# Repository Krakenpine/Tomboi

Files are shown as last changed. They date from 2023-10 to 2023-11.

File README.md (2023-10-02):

# Tomboi
 Sample player with Daisy

 Very overengineered with effects and tonally playable multisampled sounds.
 Currently this repository includes only seven drum samples from free libraries, using raw multisamples from rompler-synth woud probably be a copyright violation, so I need to create my own for public examples.

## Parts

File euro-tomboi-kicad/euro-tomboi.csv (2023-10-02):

Source: | E:\Daisy\Tomboi\euro-tomboi-kicad\euro-tomboi.kicad_sch
Date: | 02/10/2023 11:10:50
Tool: | Eeschema (6.0.0)
Generator: | C:\Program Files\KiCad\6.0\bin\scripting\plugins/bom_csv_grouped_by_value.py
Component Count: | 72
Individual Components:
Item | Qty | Reference(s) | Value | LibPart | Footprint | Datasheet
 |  | C1 | 10n | Device:C | Capacitor_THT:C_Disc_D5.0mm_W2.5mm_P5.00mm | ~
 |  | C2 | 10n | Device:C | Capacitor_THT:C_Disc_D5.0mm_W2.5mm_P5.00mm | ~
 |  | C3 | 10n | Device:C | Capacitor_THT:C_Disc_D5.0mm_W2.5mm_P5.00mm | ~
 |  | C4 | 100n | Device:C | Capacitor_THT:C_Disc_D5.0mm_W2.5mm_P5.00mm | ~
 |  | C5 | 100n | Device:C | Capacitor_THT:C_Disc_D5.0mm_W2.5mm_P5.00mm | ~
 |  | C6 | 100n | Device:C | Capacitor_THT:C_Disc_D5.0mm_W2.5mm_P5.00mm | ~
 |  | C7 | 10u | Device:C_Polarized | Capacitor_THT:CP_Radial_D5.0mm_P2.50mm | ~
 |  | C8 | 10u | Device:C_Polarized | Capacitor_THT:CP_Radial_D5.0mm_P2.50mm | ~
 |  | C9 | 100n | Device:C | Capacitor_THT:C_Disc_D5.0mm_W2.5mm_P5.00mm | ~
 |  | C10 | 100n | Device:C | Capacitor_THT:C_Disc_D5.0mm_W2.5mm_P5.00mm | ~
 |  | D1 | BAT42 | Diode:BAT42 | Diode_THT:D_DO-35_SOD27_P7.62mm_Horizontal | http://www.vishay.com/docs/85660/bat42.pdf
 |  | D2 | BAT42 | Diode:BAT42 | Diode_THT:D_DO-35_SOD27_P7.62mm_Horizontal | http://www.vishay.com/docs/85660/bat42.pdf
 |  | D3 | BAT42 | Diode:BAT42 | Diode_THT:D_DO-35_SOD27_P7.62mm_Horizontal | http://www.vishay.com/docs/85660/bat42.pdf
 |  | D4 | BAT42 | Diode:BAT42 | Diode_THT:D_DO-35_SOD27_P7.62mm_Horizontal | http://www.vishay.com/docs/85660/bat42.pdf
 |  | D5 | BAT42 | Diode:BAT42 | Diode_THT:D_DO-35_SOD27_P7.62mm_Horizontal | http://www.vishay.com/docs/85660/bat42.pdf
 |  | D6 | BAT42 | Diode:BAT42 | Diode_THT:D_DO-35_SOD27_P7.62mm_Horizontal | http://www.vishay.com/docs/85660/bat42.pdf
 |  | D7 | BAT42 | Diode:BAT42 | Diode_THT:D_DO-35_SOD27_P7.62mm_Horizontal | http://www.vishay.com/docs/85660/bat42.pdf
 |  | D8 | BAT42 | Diode:BAT42 | Diode_THT:D_DO-35_SOD27_P7.62mm_Horizontal | http://www.vishay.com/docs/85660/bat42.pdf
 |  | J1 | Output | Connector:AudioJack2_SwitchT | omat:Jack_3.5mm_QingPu_WQP-PJ398SM_Vertical_CircularHoles_mid | ~
 |  | J2 | Trig_1 | Connector:AudioJack2_SwitchT | omat:Jack_3.5mm_QingPu_WQP-PJ398SM_Vertical_CircularHoles_mid | ~
 |  | J3 | Trig_2 | Connector:AudioJack2_SwitchT | omat:Jack_3.5mm_QingPu_WQP-PJ398SM_Vertical_CircularHoles_mid | ~
 |  | J4 | Trig_3 | Connector:AudioJack2_SwitchT | omat:Jack_3.5mm_QingPu_WQP-PJ398SM_Vertical_CircularHoles_mid | ~
 |  | J5 | CV_1 | Connector:AudioJack2_SwitchT | omat:Jack_3.5mm_QingPu_WQP-PJ398SM_Vertical_CircularHoles_mid | ~
 |  | J6 | CV_2 | Connector:AudioJack2_SwitchT | omat:Jack_3.5mm_QingPu_WQP-PJ398SM_Vertical_CircularHoles_mid | ~
 |  | J7 | CV_3 | Connector:AudioJack2_SwitchT | omat:Jack_3.5mm_QingPu_WQP-PJ398SM_Vertical_CircularHoles_mid | ~
 |  | J8 | Conn_01x16_Female | Connector:Conn_01x16_Female | Connector_PinSocket_2.54mm:PinSocket_1x16_P2.54mm_Vertical | ~
 |  | J9 | Conn_01x16_Male | Connector:Conn_01x16_Male | Connector_PinHeader_2.54mm:PinHeader_1x16_P2.54mm_Vertical | ~
 |  | J10 | Conn_02x05_Odd_Even | Connector_Generic:Conn_02x05_Odd_Even | Connector_PinHeader_2.54mm:PinHeader_2x05_P2.54mm_Vertical | ~
 |  | R1 | 66.5k | Device:R | omat:Omaresistor2 | ~
 |  | R2 | 200k | Device:R | omat:Omaresistor2 | ~
 |  | R3 | 66.5k | Device:R | omat:Omaresistor2 | ~
 |  | R4 | 200k | Device:R | omat:Omaresistor2 | ~
 |  | R5 | 66.5k | Device:R | omat:Omaresistor2 | ~
 |  | R6 | 200k | Device:R | omat:Omaresistor2 | ~
 |  | R7 | 1k | Device:R | omat:Omaresistor2 | ~
 |  | R8 | 1k | Device:R | omat:Omaresistor2 | ~
 |  | R9 | 1k | Device:R | omat:Omaresistor2 | ~
 |  | R10 | 200k | Device:R | omat:Omaresistor2 | ~
 |  | R11 | 200k | Device:R | omat:Omaresistor2 | ~
 |  | R12 | 200k | Device:R | omat:Omaresistor2 | ~
 |  | R13 | 66.5k | Device:R | omat:Omaresistor2 | ~
 |  | R14 | 66.5k | Device:R | omat:Omaresistor2 | ~
 |  | R15 | 66.5k | Device:R | omat:Omaresistor2 | ~
 |  | R16 | 1k | Device:R | omat:Omaresistor2 | ~
 |  | R17 | 1k | Device:R | omat:Omaresistor2 | ~
 |  | R18 | 1k | Device:R | omat:Omaresistor2 | ~
 |  | R19 | 1k | Device:R | omat:Omaresistor2 | ~
 |  | R20 | 1k | Device:R | omat:Omaresistor2 | ~
 |  | R21 | 1k | Device:R | omat:Omaresistor2 | ~
 |  | R22 | 1k | Device:R | omat:Omaresistor2 | ~
 |  | R23 | 10k | Device:R | omat:Omaresistor2 | ~
 |  | R24 | 20k | Device:R | omat:Omaresistor2 | ~
 |  | R25 | 1k | Device:R | omat:Omaresistor2 | ~
 |  | R26 | 2k | Device:R | omat:Omaresistor2 | ~
 |  | RV1 | Sample1pitch | Device:R_Potentiometer | omat:Potentiometer_Alpha_RD901F-40-00D_Single_Vertical_CircularHoles3D | ~
 |  | RV2 | Sample1cv_attn | Device:R_Potentiometer | omat:Potentiometer_Alpha_RD901F-40-00D_Single_Vertical_CircularHoles3D | ~
 |  | RV3 | Sample1select | Device:R_Potentiometer | omat:Potentiometer_Alpha_RD901F-40-00D_Single_Vertical_CircularHoles3D | ~
 |  | RV4 | Sample2pitch | Device:R_Potentiometer | omat:Potentiometer_Alpha_RD901F-40-00D_Single_Vertical_CircularHoles3D | ~
 |  | RV5 | Sample2cv_attn | Device:R_Potentiometer | omat:Potentiometer_Alpha_RD901F-40-00D_Single_Vertical_CircularHoles3D | ~
 |  | RV6 | Sample2select | Device:R_Potentiometer | omat:Potentiometer_Alpha_RD901F-40-00D_Single_Vertical_CircularHoles3D | ~
 |  | RV7 | Sample3pitch | Device:R_Potentiometer | omat:Potentiometer_Alpha_RD901F-40-00D_Single_Vertical_CircularHoles3D | ~
 |  | RV8 | Sample3cv_attn | Device:R_Potentiometer | omat:Potentiometer_Alpha_RD901F-40-00D_Single_Vertical_CircularHoles3D | ~
 |  | RV9 | Sample3select | Device:R_Potentiometer | omat:Potentiometer_Alpha_RD901F-40-00D_Single_Vertical_CircularHoles3D | ~
 |  | RV10 | Reverb_mix | Device:R_Potentiometer | omat:Potentiometer_Alpha_RD901F-40-00D_Single_Vertical_CircularHoles3D | ~
 |  | RV11 | Reverb_feedback | Device:R_Potentiometer | omat:Potentiometer_Alpha_RD901F-40-00D_Single_Vertical_CircularHoles3D | ~
 |  | RV12 | Reverb_lowpass | Device:R_Potentiometer | omat:Potentiometer_Alpha_RD901F-40-00D_Single_Vertical_CircularHoles3D | ~
 |  | SW1 | SW_SPDT | Switch:SW_SPDT | omat:submini switch | ~
 |  | U1 | MCP6002-xP | Amplifier_Operational:MCP6002-xP | Package_DIP:DIP-8_W7.62mm | http://ww1.microchip.com/downloads/en/DeviceDoc/21733j.pdf
 |  | U2 | MCP6002-xP | Amplifier_Operational:MCP6002-xP | Package_DIP:DIP-8_W7.62mm | http://ww1.microchip.com/downloads/en/DeviceDoc/21733j.pdf
 |  | U3 | Daisy_Seed | omat:Daisy_Seed | omat:Daisy Seed
 |  | U4 | TL071 | Amplifier_Operational:TL071 | Package_DIP:DIP-8_W7.62mm | http://www.ti.com/lit/ds/symlink/tl071.pdf
 |  | U5 | LM4040LP-10 | Reference_Voltage:LM4040LP-10 | Package_TO_SOT_THT:TO-92_Inline_Wide | http://www.ti.com/lit/ds/symlink/lm4040-n.pdf
Collated Components:
Item | Qty | Reference(s) | Value | LibPart | Footprint | Datasheet
1 | 3 | C1, C2, C3 | 10n | Device:C | Capacitor_THT:C_Disc_D5.0mm_W2.5mm_P5.00mm | ~
2 | 5 | C4, C5, C6, C9, C10 | 100n | Device:C | Capacitor_THT:C_Disc_D5.0mm_W2.5mm_P5.00mm | ~
3 | 2 | C7, C8 | 10u | Device:C_Polarized | Capacitor_THT:CP_Radial_D5.0mm_P2.50mm | ~
4 | 8 | D1, D2, D3, D4, D5, D6, D7, D8 | BAT42 | Diode:BAT42 | Diode_THT:D_DO-35_SOD27_P7.62mm_Horizontal | http://www.vishay.com/docs/85660/bat42.pdf
5 | 1 | J1 | Output | Connector:AudioJack2_SwitchT | omat:Jack_3.5mm_QingPu_WQP-PJ398SM_Vertical_CircularHoles_mid | ~
6 | 1 | J2 | Trig_1 | Connector:AudioJack2_SwitchT | omat:Jack_3.5mm_QingPu_WQP-PJ398SM_Vertical_CircularHoles_mid | ~
7 | 1 | J3 | Trig_2 | Connector:AudioJack2_SwitchT | omat:Jack_3.5mm_QingPu_WQP-PJ398SM_Vertical_CircularHoles_mid | ~
8 | 1 | J4 | Trig_3 | Connector:AudioJack2_SwitchT | omat:Jack_3.5mm_QingPu_WQP-PJ398SM_Vertical_CircularHoles_mid | ~
9 | 1 | J5 | CV_1 | Connector:AudioJack2_SwitchT | omat:Jack_3.5mm_QingPu_WQP-PJ398SM_Vertical_CircularHoles_mid | ~
10 | 1 | J6 | CV_2 | Connector:AudioJack2_SwitchT | omat:Jack_3.5mm_QingPu_WQP-PJ398SM_Vertical_CircularHoles_mid | ~
11 | 1 | J7 | CV_3 | Connector:AudioJack2_SwitchT | omat:Jack_3.5mm_QingPu_WQP-PJ398SM_Vertical_CircularHoles_mid | ~
12 | 1 | J8 | Conn_01x16_Female | Connector:Conn_01x16_Female | Connector_PinSocket_2.54mm:PinSocket_1x16_P2.54mm_Vertical | ~
13 | 1 | J9 | Conn_01x16_Male | Connector:Conn_01x16_Male | Connector_PinHeader_2.54mm:PinHeader_1x16_P2.54mm_Vertical | ~
14 | 1 | J10 | Conn_02x05_Odd_Even | Connector_Generic:Conn_02x05_Odd_Even | Connector_PinHeader_2.54mm:PinHeader_2x05_P2.54mm_Vertical | ~
15 | 6 | R1, R3, R5, R13, R14, R15 | 66.5k | Device:R | omat:Omaresistor2 | ~
16 | 6 | R2, R4, R6, R10, R11, R12 | 200k | Device:R | omat:Omaresistor2 | ~
17 | 11 | R7, R8, R9, R16, R17, R18, R19, R20, R21, R22, R25 | 1k | Device:R | omat:Omaresistor2 | ~
18 | 1 | R23 | 10k | Device:R | omat:Omaresistor2 | ~
19 | 1 | R24 | 20k | Device:R | omat:Omaresistor2 | ~
20 | 1 | R26 | 2k | Device:R | omat:Omaresistor2 | ~
21 | 1 | RV1 | Sample1pitch | Device:R_Potentiometer | omat:Potentiometer_Alpha_RD901F-40-00D_Single_Vertical_CircularHoles3D | ~
22 | 1 | RV2 | Sample1cv_attn | Device:R_Potentiometer | omat:Potentiometer_Alpha_RD901F-40-00D_Single_Vertical_CircularHoles3D | ~
23 | 1 | RV3 | Sample1select | Device:R_Potentiometer | omat:Potentiometer_Alpha_RD901F-40-00D_Single_Vertical_CircularHoles3D | ~
24 | 1 | RV4 | Sample2pitch | Device:R_Potentiometer | omat:Potentiometer_Alpha_RD901F-40-00D_Single_Vertical_CircularHoles3D | ~
25 | 1 | RV5 | Sample2cv_attn | Device:R_Potentiometer | omat:Potentiometer_Alpha_RD901F-40-00D_Single_Vertical_CircularHoles3D | ~
26 | 1 | RV6 | Sample2select | Device:R_Potentiometer | omat:Potentiometer_Alpha_RD901F-40-00D_Single_Vertical_CircularHoles3D | ~
27 | 1 | RV7 | Sample3pitch | Device:R_Potentiometer | omat:Potentiometer_Alpha_RD901F-40-00D_Single_Vertical_CircularHoles3D | ~
28 | 1 | RV8 | Sample3cv_attn | Device:R_Potentiometer | omat:Potentiometer_Alpha_RD901F-40-00D_Single_Vertical_CircularHoles3D | ~
29 | 1 | RV9 | Sample3select | Device:R_Potentiometer | omat:Potentiometer_Alpha_RD901F-40-00D_Single_Vertical_CircularHoles3D | ~
30 | 1 | RV10 | Reverb_mix | Device:R_Potentiometer | omat:Potentiometer_Alpha_RD901F-40-00D_Single_Vertical_CircularHoles3D | ~
31 | 1 | RV11 | Reverb_feedback | Device:R_Potentiometer | omat:Potentiometer_Alpha_RD901F-40-00D_Single_Vertical_CircularHoles3D | ~
32 | 1 | RV12 | Reverb_lowpass | Device:R_Potentiometer | omat:Potentiometer_Alpha_RD901F-40-00D_Single_Vertical_CircularHoles3D | ~
33 | 1 | SW1 | SW_SPDT | Switch:SW_SPDT | omat:submini switch | ~
34 | 2 | U1, U2 | MCP6002-xP | Amplifier_Operational:MCP6002-xP | Package_DIP:DIP-8_W7.62mm | http://ww1.microchip.com/downloads/en/DeviceDoc/21733j.pdf
35 | 1 | U3 | Daisy_Seed | omat:Daisy_Seed | omat:Daisy Seed
36 | 1 | U4 | TL071 | Amplifier_Operational:TL071 | Package_DIP:DIP-8_W7.62mm | http://www.ti.com/lit/ds/symlink/tl071.pdf
37 | 1 | U5 | LM4040LP-10 | Reference_Voltage:LM4040LP-10 | Package_TO_SOT_THT:TO-92_Inline_Wide | http://www.ti.com/lit/ds/symlink/lm4040-n.pdf

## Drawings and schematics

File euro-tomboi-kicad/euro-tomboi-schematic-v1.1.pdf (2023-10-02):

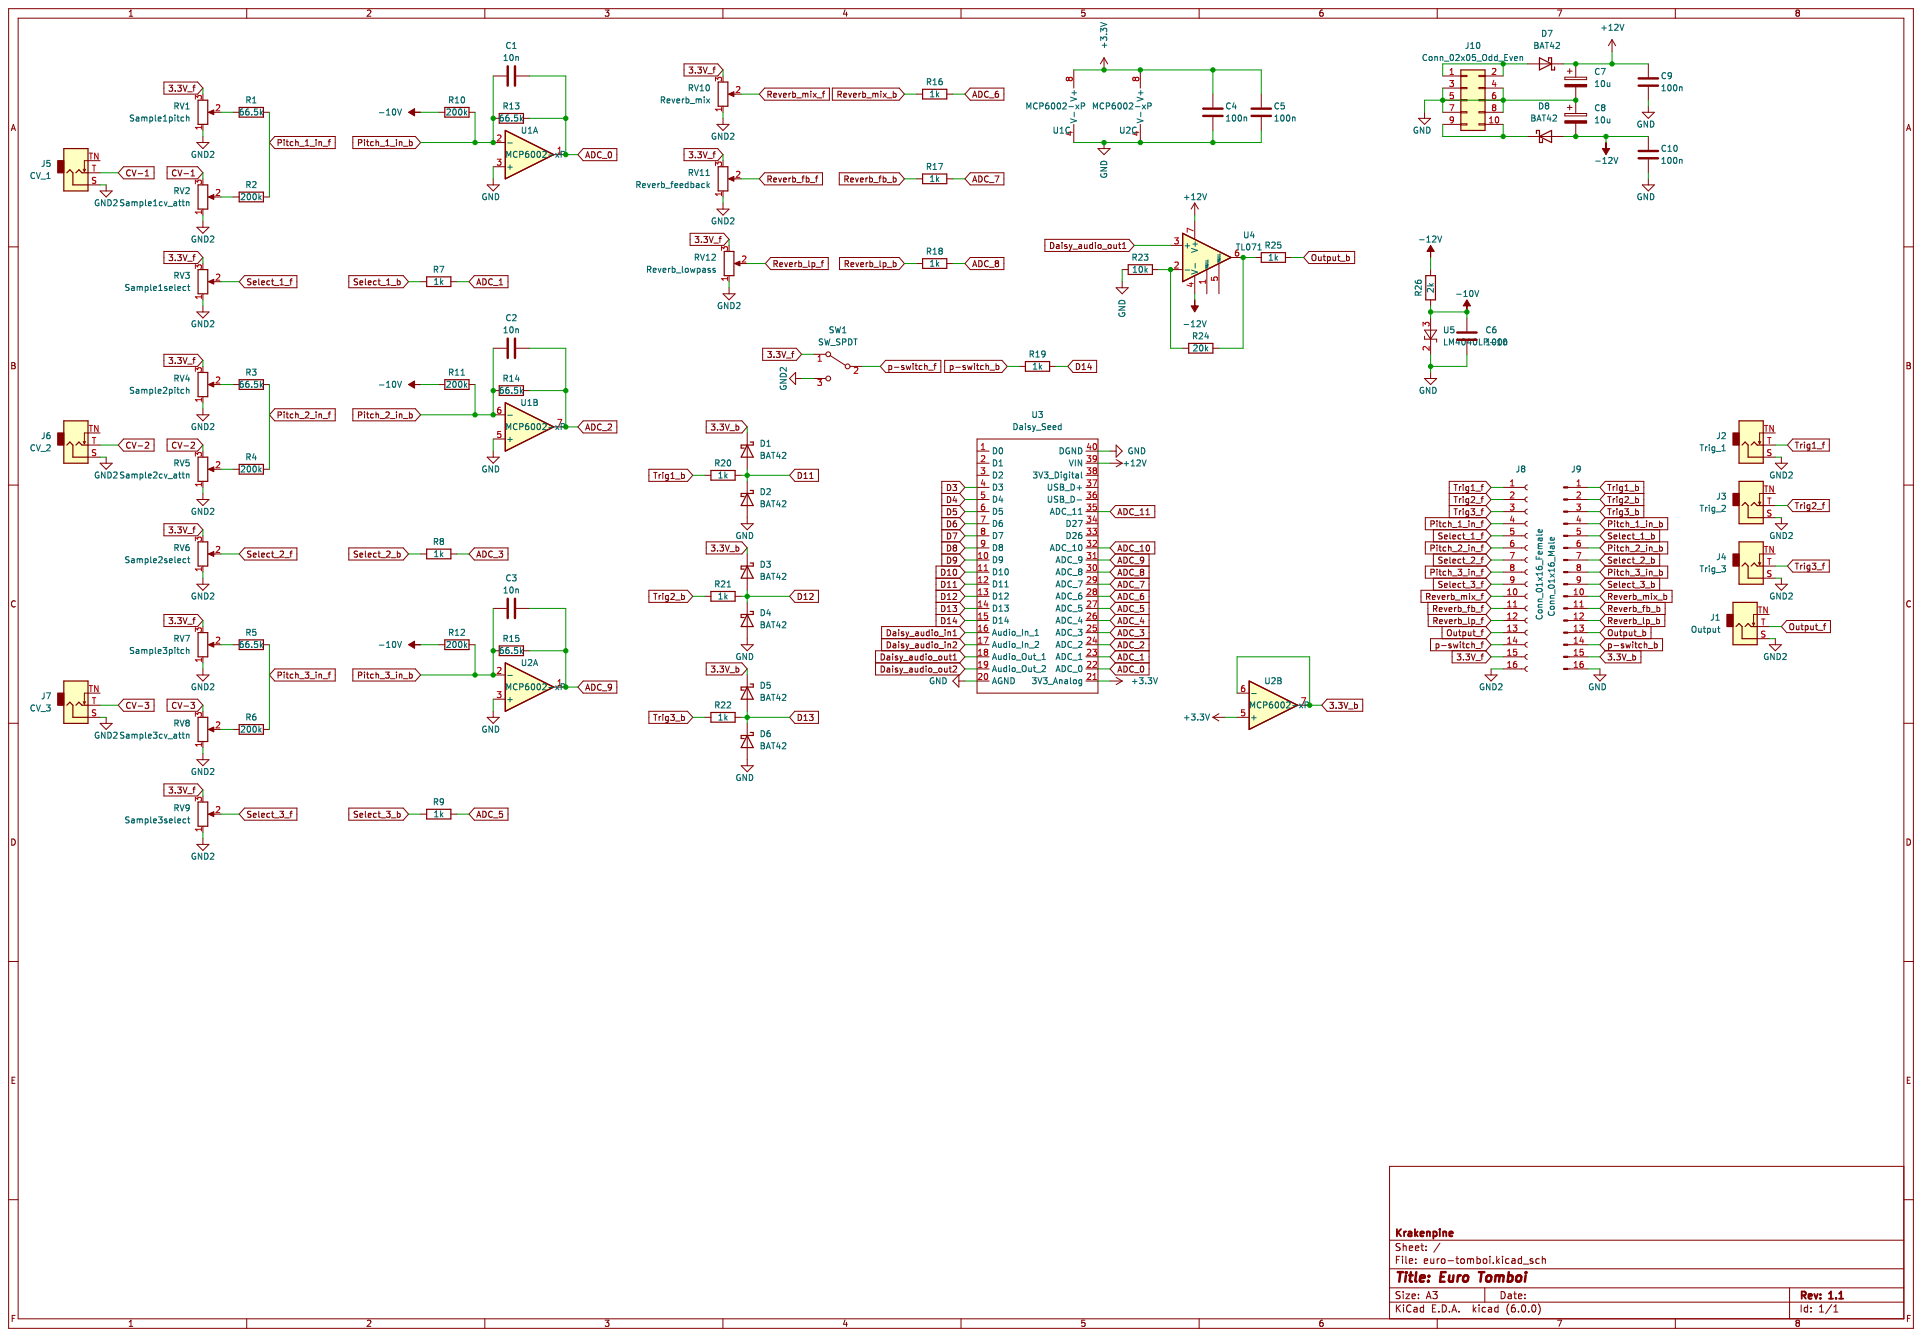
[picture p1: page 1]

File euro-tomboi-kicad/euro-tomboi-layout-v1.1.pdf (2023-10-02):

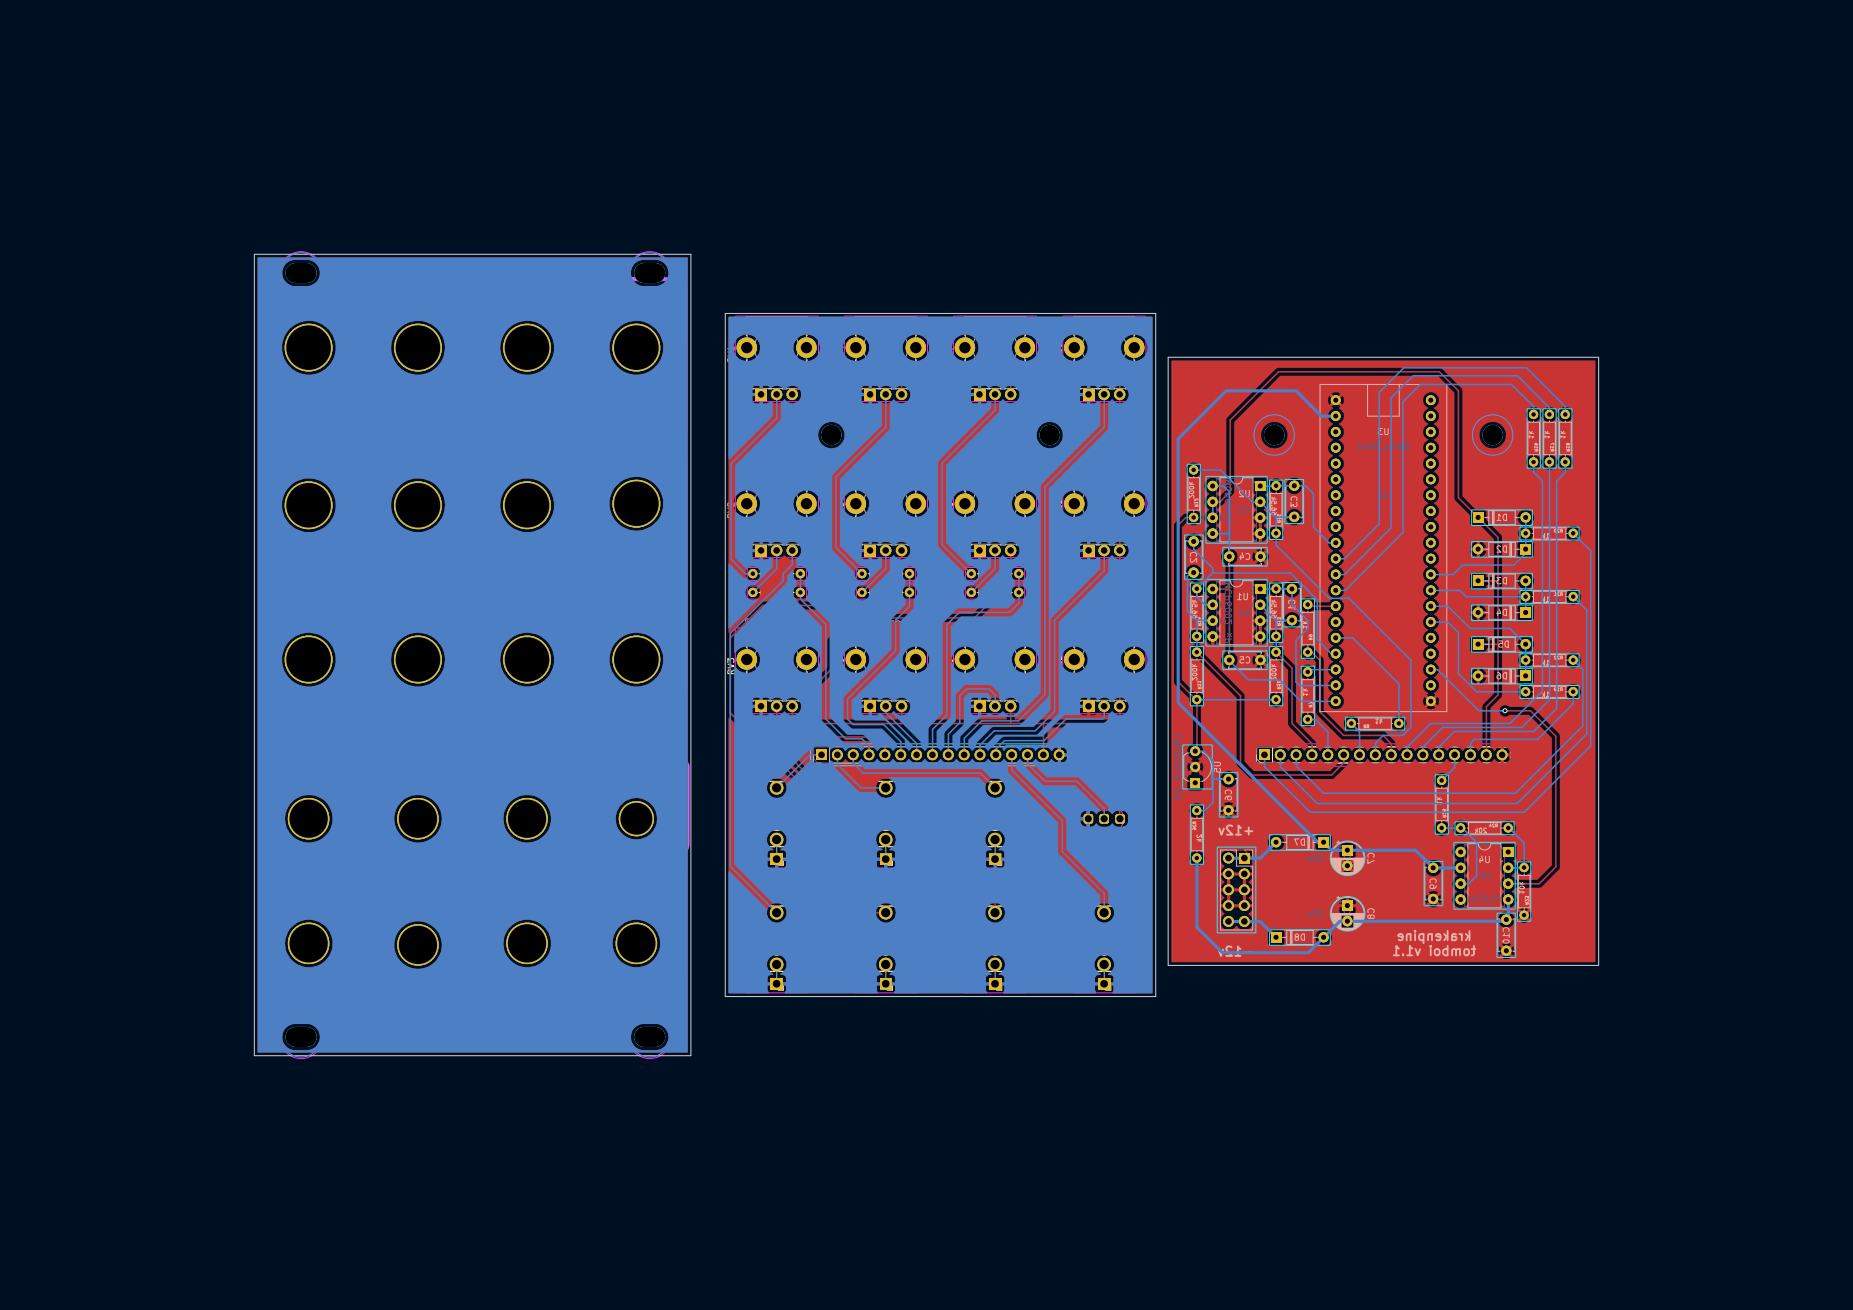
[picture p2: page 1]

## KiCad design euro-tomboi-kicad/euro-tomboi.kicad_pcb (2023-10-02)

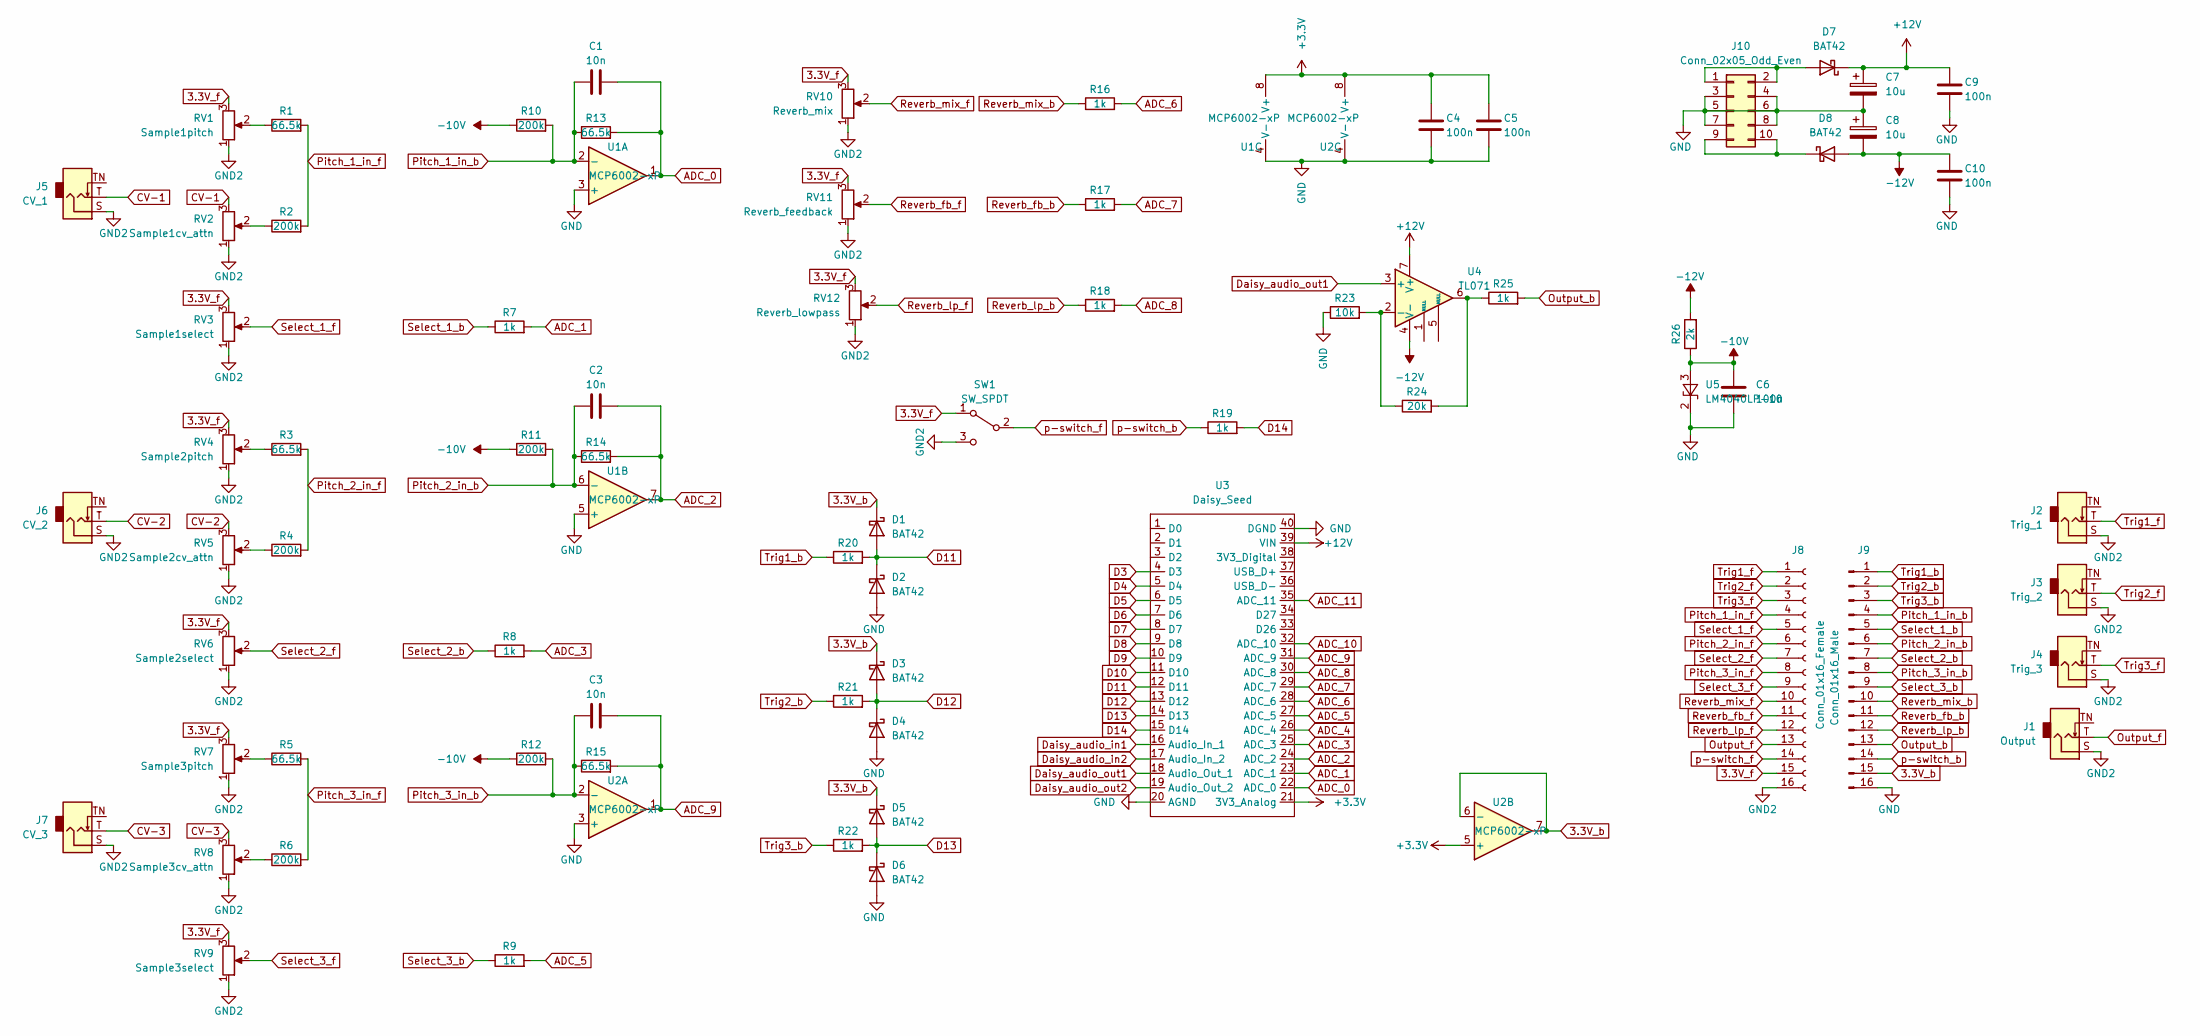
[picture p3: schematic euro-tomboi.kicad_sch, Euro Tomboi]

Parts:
C1, C2, C3: 10n; C_Disc_D5.0mm_W2.5mm_P5.00mm
C4, C5, C6, C9, C10: 100n; C_Disc_D5.0mm_W2.5mm_P5.00mm
C7, C8: 10u; CP_Radial_D5.0mm_P2.50mm
D1, D2, D3, D4, D5, D6, D7, D8: BAT42; D_DO-35_SOD27_P7.62mm_Horizontal
J1: Output; Jack_3.5mm_QingPu_WQP-PJ398SM_Vertical_CircularHoles_mid
J2: Trig_1; Jack_3.5mm_QingPu_WQP-PJ398SM_Vertical_CircularHoles_mid
J3: Trig_2; Jack_3.5mm_QingPu_WQP-PJ398SM_Vertical_CircularHoles_mid
J4: Trig_3; Jack_3.5mm_QingPu_WQP-PJ398SM_Vertical_CircularHoles_mid
J5: CV_1; Jack_3.5mm_QingPu_WQP-PJ398SM_Vertical_CircularHoles_mid
J6: CV_2; Jack_3.5mm_QingPu_WQP-PJ398SM_Vertical_CircularHoles_mid
J7: CV_3; Jack_3.5mm_QingPu_WQP-PJ398SM_Vertical_CircularHoles_mid
J8: Conn_01x16_Female; PinSocket_1x16_P2.54mm_Vertical
J9: Conn_01x16_Male; PinHeader_1x16_P2.54mm_Vertical
J10: Conn_02x05_Odd_Even; PinHeader_2x05_P2.54mm_Vertical
R1, R3, R5, R13, R14, R15: 66.5k; Omaresistor2
R2, R4, R6, R10, R11, R12: 200k; Omaresistor2
R7, R8, R9, R16, R17, R18, R19, R20, R21, R22, R25: 1k; Omaresistor2
R23: 10k; Omaresistor2
R24: 20k; Omaresistor2
R26: 2k; Omaresistor2
RV1: Sample1pitch; Potentiometer_Alpha_RD901F-40-00D_Single_Vertical_CircularH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
RV2: Sample1cv_attn; Potentiometer_Alpha_RD901F-40-00D_Single_Vertical_CircularH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
RV3: Sample1select; Potentiometer_Alpha_RD901F-40-00D_Single_Vertical_CircularH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
RV4: Sample2pitch; Potentiometer_Alpha_RD901F-40-00D_Single_Vertical_CircularH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
RV5: Sample2cv_attn; Potentiometer_Alpha_RD901F-40-00D_Single_Vertical_CircularH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
RV6: Sample2select; Potentiometer_Alpha_RD901F-40-00D_Single_Vertical_CircularH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
RV7: Sample3pitch; Potentiometer_Alpha_RD901F-40-00D_Single_Vertical_CircularH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
RV8: Sample3cv_attn; Potentiometer_Alpha_RD901F-40-00D_Single_Vertical_CircularH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
RV9: Sample3select; Potentiometer_Alpha_RD901F-40-00D_Single_Vertical_CircularH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
RV10: Reverb_mix; Potentiometer_Alpha_RD901F-40-00D_Single_Vertical_CircularH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
RV11: Reverb_feedback; Potentiometer_Alpha_RD901F-40-00D_Single_Vertical_CircularH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
RV12: Reverb_lowpass; Potentiometer_Alpha_RD901F-40-00D_Single_Vertical_CircularH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
SW1: SW_SPDT; submini switch
U1, U2: MCP6002-xP; DIP-8_W7.62mm
U3: Daisy_Seed; Daisy Seed
U4: TL071; DIP-8_W7.62mm
U5: LM4040LP-10; TO-92_Inline_Wide

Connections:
3.3V_b: D1.1 (K), D3.1 (K), D5.1 (K), J9.15, U2.6 (-), U2.7
3.3V_f: J8.15, RV1.3, RV3.3, RV4.3, RV6.3, RV7.3, RV9.3, RV10.3, RV11.3, RV12.3, SW1.1 (A)
+3V3: C4.1, C5.1, U1.8 (V+), U2.5 (+), U2.8 (V+), U3.21 (3V3_Analog)
+12V: C7.1, C9.1, D7.1 (K), U3.39 (VIN), U4.7 (V+)
-10V: C6.1, R10.1, R11.1, R12.1, R26.1, U5.3 (A)
-12V: C8.2, C10.1, D8.2 (A), R26.2, U4.4 (V-)
ADC_0: C1.2, R13.2, U1.1, U3.22 (ADC_0)
ADC_1: R7.2, U3.23 (ADC_1)
ADC_2: C2.2, R14.2, U1.7, U3.24 (ADC_2)
ADC_3: R8.2, U3.25 (ADC_3)
ADC_4: U3.26 (ADC_4)
ADC_5: R9.2, U3.27 (ADC_5)
ADC_6: R16.2, U3.28 (ADC_6)
ADC_7: R17.2, U3.29 (ADC_7)
ADC_8: R18.2, U3.30 (ADC_8)
ADC_9: C3.2, R15.2, U2.1, U3.31 (ADC_9)
ADC_10: U3.32 (ADC_10)
ADC_11: U3.35 (ADC_11)
CV-1: J5.T, RV2.3
CV-2: J6.T, RV5.3
CV-3: J7.T, RV8.3
D3: U3.4 (D3)
D4: U3.5 (D4)
D5: U3.6 (D5)
D6: U3.7 (D6)
D7: U3.8 (D7)
D8: U3.9 (D8)
D9: U3.10 (D9)
D10: U3.11 (D10)
D11: D1.2 (A), D2.1 (K), R20.2, U3.12 (D11)
D12: D3.2 (A), D4.1 (K), R21.2, U3.13 (D12)
D13: D5.2 (A), D6.1 (K), R22.2, U3.14 (D13)
D14: R19.2, U3.15 (D14)
Daisy_audio_in1: U3.16 (Audio_In_1)
Daisy_audio_in2: U3.17 (Audio_In_2)
Daisy_audio_out1: U3.18 (Audio_Out_1), U4.3 (+)
Daisy_audio_out2: U3.19 (Audio_Out_2)
GND: C4.2, C5.2, C6.2, C7.2, C8.1, C9.2, C10.2, D2.2 (A), D4.2 (A), D6.2 (A), J9.16, J10.3, J10.4, J10.5, J10.6, J10.7, J10.8, R23.1, U1.3 (+), U1.4 (V-), U1.5 (+), U2.3 (+), U2.4 (V-), U3.20 (AGND), U3.40 (DGND), U5.2 (K)
GND2: J1.S, J2.S, J3.S, J4.S, J5.S, J6.S, J7.S, J8.16, RV1.1, RV2.1, RV3.1, RV4.1, RV5.1, RV6.1, RV7.1, RV8.1, RV9.1, RV10.1, RV11.1, RV12.1, SW1.3 (C)
unnamed: D7.2 (A), J10.1, J10.2
unnamed: D8.1 (K), J10.9, J10.10
unnamed: R1.1, RV1.2
unnamed: R2.1, RV2.2
unnamed: R3.1, RV4.2
unnamed: R4.1, RV5.2
unnamed: R5.1, RV7.2
unnamed: R6.1, RV8.2
unnamed: R23.2, R24.1, U4.2 (-)
unnamed: R24.2, R25.1, U4.6
Output_b: J9.13, R25.2
Output_f: J1.T, J8.13
Pitch_1_in_b: C1.1, J9.4, R10.2, R13.1, U1.2 (-)
Pitch_1_in_f: J8.4, R1.2, R2.2
Pitch_2_in_b: C2.1, J9.6, R11.2, R14.1, U1.6 (-)
Pitch_2_in_f: J8.6, R3.2, R4.2
Pitch_3_in_b: C3.1, J9.8, R12.2, R15.1, U2.2 (-)
Pitch_3_in_f: J8.8, R5.2, R6.2
Reverb_fb_b: J9.11, R17.1
Reverb_fb_f: J8.11, RV11.2
Reverb_lp_b: J9.12, R18.1
Reverb_lp_f: J8.12, RV12.2
Reverb_mix_b: J9.10, R16.1
Reverb_mix_f: J8.10, RV10.2
Select_1_b: J9.5, R7.1
Select_1_f: J8.5, RV3.2
Select_2_b: J9.7, R8.1
Select_2_f: J8.7, RV6.2
Select_3_b: J9.9, R9.1
Select_3_f: J8.9, RV9.2
Trig1_b: J9.1, R20.1
Trig1_f: J2.T, J8.1
Trig2_b: J9.2, R21.1
Trig2_f: J3.T, J8.2
Trig3_b: J9.3, R22.1
Trig3_f: J4.T, J8.3
p-switch_b: J9.14, R19.1
p-switch_f: J8.14, SW1.2 (B)

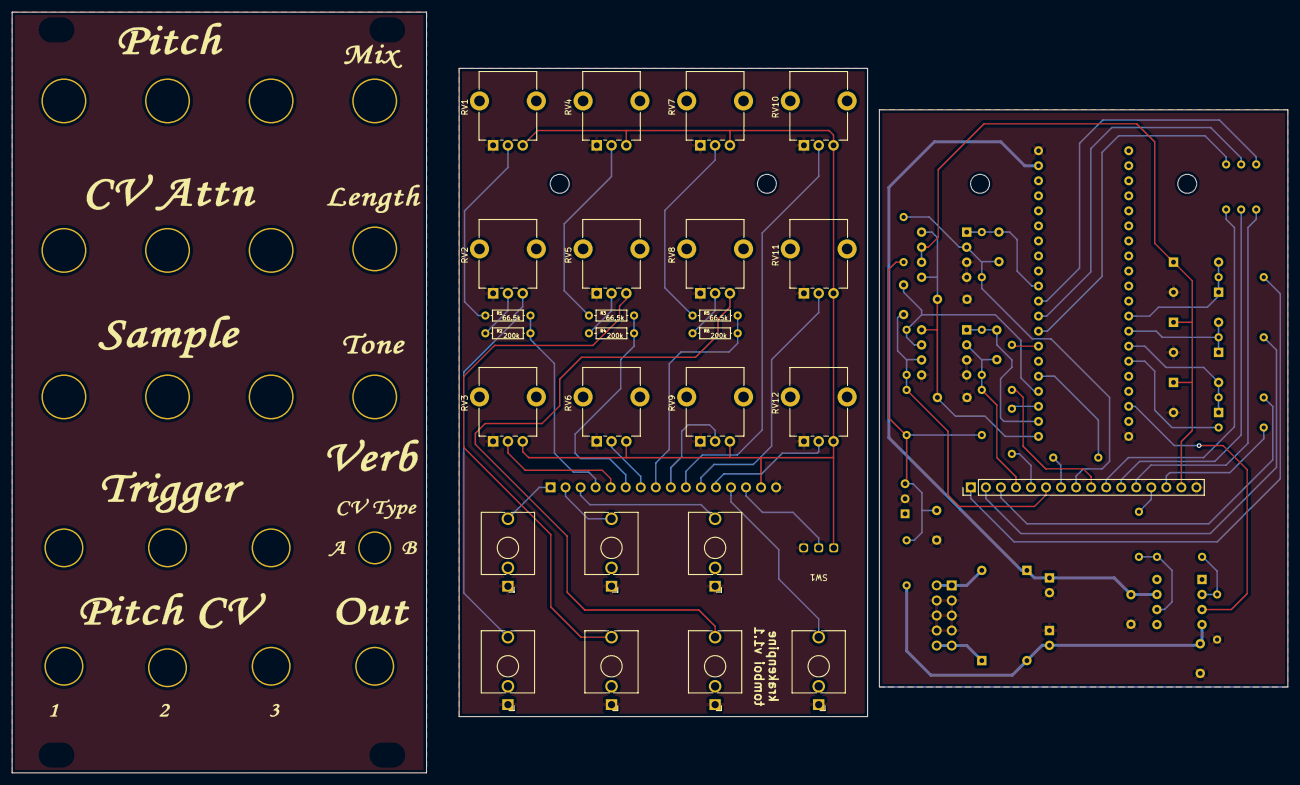
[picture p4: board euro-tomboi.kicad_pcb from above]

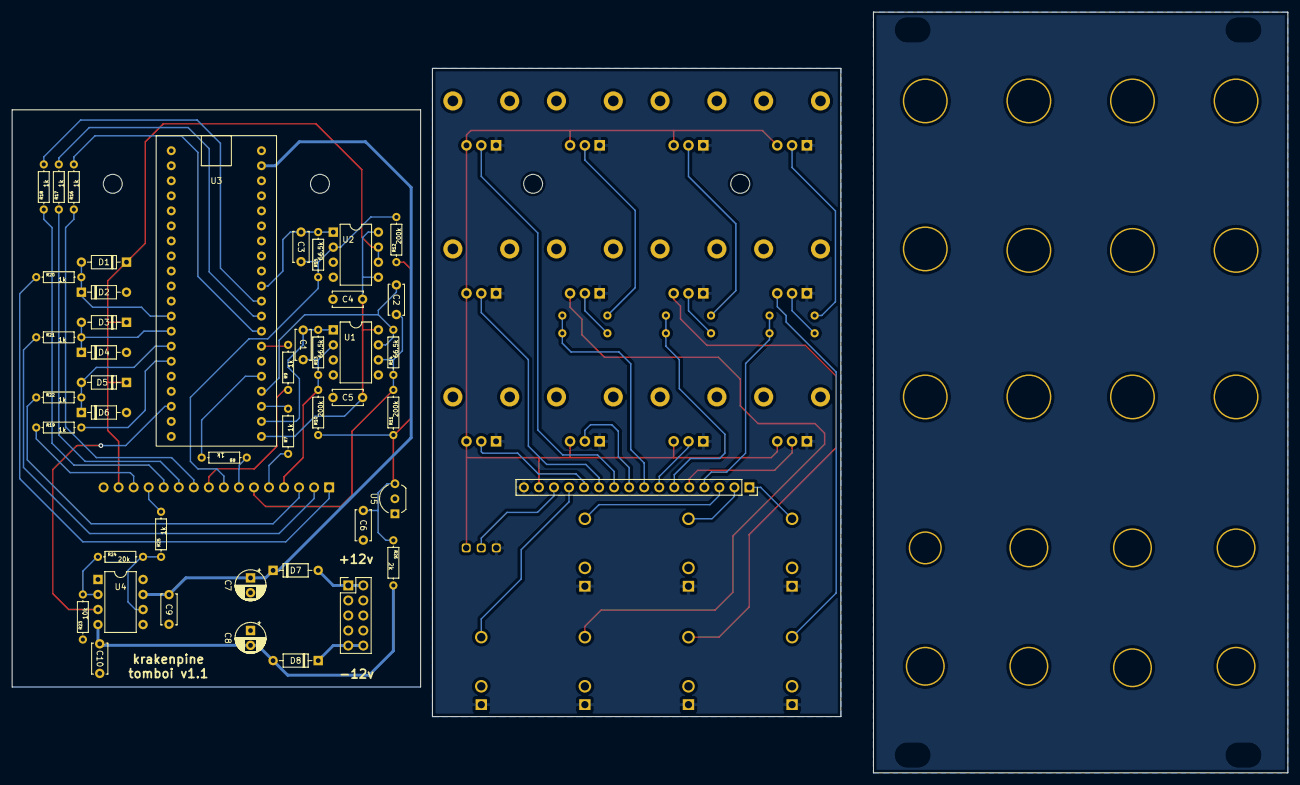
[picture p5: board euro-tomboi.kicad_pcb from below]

Board: 2 copper layers, 215.5 x 128.5 mm, 73 parts (45 on the bottom side), 63 nets.

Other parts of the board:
Ref**: Val**; euro-tomboi-kansi1

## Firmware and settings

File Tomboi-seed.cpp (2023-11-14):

#include "daisy_pod.h"
#include "daisysp.h"
#include <math.h>
#include <vector>
#include <string>
#include "samples/tom1.cpp"
#include "samples/tom2.cpp"
#include "samples/tom3.cpp"
#include "samples/tom4.cpp"
#include "samples/tom5.cpp"
#include "samples/tom6.cpp"
#include "samples/tom7.cpp"

#include "midi_notes.cpp"
#include "sample.h"
#include "voice.h"
#include "polyvoice.h"
#include "delayLP.h"
#include "chorusLP.h"
#include "tomvoice.h"

float DSY_SDRAM_BSS tom1_ram[tom1_size];
float DSY_SDRAM_BSS tom2_ram[tom2_size];
float DSY_SDRAM_BSS tom3_ram[tom3_size];
float DSY_SDRAM_BSS tom4_ram[tom4_size];
float DSY_SDRAM_BSS tom5_ram[tom5_size];
float DSY_SDRAM_BSS tom6_ram[tom6_size];
float DSY_SDRAM_BSS tom7_ram[tom7_size];

using namespace daisy;
using namespace daisysp;

DaisySeed  hardware;
ReverbSc   verb;

float DSY_SDRAM_BSS buf_pitch[48000 * 4] = { 0 };

float DSY_SDRAM_BSS buf_del[48000] = { 0 };

DelayLP delay1;

float DSY_SDRAM_BSS buf_cho[4800] = { 0 };
float DSY_SDRAM_BSS buf_cho_del_pitch[48000 * 4] = { 0 };

DelayLP delay_cho;

ChorusLP chorus1;

std::vector <TomVoice> tom_voices1;
std::vector <TomVoice> tom_voices2;
std::vector <TomVoice> tom_voices3;

float base_note = 16.35;

float drywet = 0.50;

float verb_feedback = 0.90;

float verb_lowpass = 18000.0;

int dry_feedback_lowpass = 0;

int selected_sample = 0;

bool pitch_type = false;

int selected_tom1 = 0;
int selected_tom2 = 1;
int selected_tom3 = 2;

float tom_speed1 = 1.0f;
float tom_speed2 = 1.0f;
float tom_speed3 = 1.0f;

Switch trigger1;
Switch trigger2;
Switch trigger3;
Switch cv_type;

void GetReverbSample(float &outl, float &outr, float inl, float inr);

float fastTanh(float in)
{
    if (in < -3.f)
    {
        return -1.f;
    }
    else if (in > 3.f)
    {
        return 1.f;
    }
    else
    {
        float in2 = in*in;
        return in * (27.f + in2) / (27.f + in2 * 9.f);
    }
}

float cvToPitch(float cv_in)
{
    if (cv_in >= 0.5)
    {
        return 1.0f + (cv_in - 0.5f) * 3.0f;
    }
    else
    {
        return 1.0f / ((1.0f - cv_in * 2.0f) * 3.0f + 1.0f);
    }
}

int inputPitchToMidiNote(float pitch)
{
    // Voltage from 0 to 10 volts => 10 octaves + 1 semitone C-1 -> C9, 121 midi notes
    float lowest_midi_note = 0.0f; // C-1, midi note 0, 8.18 Hz
    float midi_note_range = 121.0f;
    return static_cast<int>(lowest_midi_note + pitch * midi_note_range);
}

static void  audio(AudioHandle::InterleavingInputBuffer  in,
                   AudioHandle::InterleavingOutputBuffer out,
                   size_t                                size)
{
    trigger1.Debounce();
    bool trigger1_pushed = trigger1.FallingEdge();

    trigger2.Debounce();
    bool trigger2_pushed = trigger2.FallingEdge();

    trigger3.Debounce();
    bool trigger3_pushed = trigger3.FallingEdge();

    float speed1 = 1.0f - hardware.adc.GetFloat(0);
    float speed2 = 1.0f - hardware.adc.GetFloat(2);
    float speed3 = 1.0f - hardware.adc.GetFloat(4);

    if (trigger1_pushed)
    {
        selected_tom1 = static_cast<int>((hardware.adc.GetFloat(1)) * 7.0f);
        tom_speed1 = cvToPitch(speed1);
        tom_voices1.at(selected_tom1).setSpeed(tom_speed1);
        tom_voices1.at(selected_tom1).start();
    }

    if (trigger2_pushed)
    {
        selected_tom2 = static_cast<int>((hardware.adc.GetFloat(3)) * 7.0f);
        tom_speed2 = cvToPitch(speed2);
        tom_voices2.at(selected_tom2).setSpeed(tom_speed2);
        tom_voices2.at(selected_tom2).start();
    }

    if (trigger3_pushed)
    {
        selected_tom3 = int((hardware.adc.GetFloat(5)) * 7.0f);
        tom_speed3 = cvToPitch(speed3);
        tom_voices3.at(selected_tom3).setSpeed(tom_speed3);
        tom_voices3.at(selected_tom3).start();
    }

    cv_type.Debounce();
    if (cv_type.Pressed())
    {
        tom_speed1 = cvToPitch(speed1);
        tom_speed2 = cvToPitch(speed2);
        tom_speed3 = cvToPitch(speed3);
        tom_voices1.at(selected_tom1).setSpeed(tom_speed1);
        tom_voices2.at(selected_tom2).setSpeed(tom_speed2);
        tom_voices3.at(selected_tom3).setSpeed(tom_speed3);
    }

    drywet = hardware.adc.GetFloat(6) * 0.5f;
    verb_feedback = 0.5f + hardware.adc.GetFloat(7) * 0.5f;
    verb_lowpass = 18000.0 * hardware.adc.GetFloat(8);

    verb.SetFeedback(verb_feedback);
    verb.SetLpFreq(verb_lowpass);

    // Audio Loop

    float outl, outr;

    for(size_t i = 0; i < size; i += 2)
    {
        // Process

        float temp = 0;

        temp += tom_voices1.at(selected_tom1).getNextSample();
        temp += tom_voices2.at(selected_tom2).getNextSample();
        temp += tom_voices3.at(selected_tom3).getNextSample();

        temp *= 0.5;

        // Chorus and delay are not used in current sounds
        // There could be separate chorus and delay for different voices
        //temp = chorus1.process(temp);

        //temp += delay1.process(temp);

        GetReverbSample(outl, outr, temp, temp);

        outl = fastTanh(outl);
        outr = fastTanh(outr);
        out[i]     = outl;
        out[i + 1] = outr;
    }
}

void GetReverbSample(float &outl, float &outr, float inl, float inr)
{
    verb.Process(inl, inr, &outl, &outr);
    outl = drywet * outl + (1 - drywet) * inl;
    outr = drywet * outr + (1 - drywet) * inr;
}

void InitSynth(float samplerate)
{
    verb.Init(samplerate);

    verb.SetLpFreq(18000.0f);
    verb.SetFeedback(0.80f);

    delay1.Init(48000, 0.5, 0.5, 0.0, false, buf_del, buf_pitch);

    chorus1.Init(0.0, 0.5, buf_cho, buf_cho_del_pitch);

    for (int i = 0; i < tom1_size; i++) { tom1_ram[i] = static_cast<float>(tom1[i]) / 32767.0; }
    for (int i = 0; i < tom2_size; i++) { tom2_ram[i] = static_cast<float>(tom2[i]) / 32767.0; }
    for (int i = 0; i < tom3_size; i++) { tom3_ram[i] = static_cast<float>(tom3[i]) / 32767.0; }
    for (int i = 0; i < tom4_size; i++) { tom4_ram[i] = static_cast<float>(tom4[i]) / 32767.0; }
    for (int i = 0; i < tom5_size; i++) { tom5_ram[i] = static_cast<float>(tom5[i]) / 32767.0; }
    for (int i = 0; i < tom6_size; i++) { tom6_ram[i] = static_cast<float>(tom6[i]) / 32767.0; }
    for (int i = 0; i < tom7_size; i++) { tom7_ram[i] = static_cast<float>(tom7[i]) / 32767.0; }

    System::Delay(500);

    Sample tom1_sample;
    tom1_sample.Init(false);
    tom1_sample.addSample(tom1_ram, tom1_size, tom1_loop, tom1_tune, "tom1");
    TomVoice tom1_voice;
    tom1_voice.Init(tom1_sample);
    tom_voices1.push_back(tom1_voice);
    tom_voices2.push_back(tom1_voice);
    tom_voices3.push_back(tom1_voice);

    Sample tom2_sample;
    tom2_sample.Init(false);
    tom2_sample.addSample(tom2_ram, tom2_size, tom2_loop, tom2_tune, "tom2");
    TomVoice tom2_voice;
    tom2_voice.Init(tom2_sample);
    tom_voices1.push_back(tom2_voice);
    tom_voices2.push_back(tom2_voice);
    tom_voices3.push_back(tom2_voice);

    Sample tom3_sample;
    tom3_sample.Init(false);
    tom3_sample.addSample(tom3_ram, tom3_size, tom3_loop, tom3_tune, "tom3");
    TomVoice tom3_voice;
    tom3_voice.Init(tom3_sample);
    tom_voices1.push_back(tom3_voice);
    tom_voices2.push_back(tom3_voice);
    tom_voices3.push_back(tom3_voice);

    Sample tom4_sample;
    tom4_sample.Init(false);
    tom4_sample.addSample(tom4_ram, tom4_size, tom4_loop, tom4_tune, "tom4");
    TomVoice tom4_voice;
    tom4_voice.Init(tom4_sample);
    tom_voices1.push_back(tom4_voice);
    tom_voices2.push_back(tom4_voice);
    tom_voices3.push_back(tom4_voice);

    Sample tom5_sample;
    tom5_sample.Init(false);
    tom5_sample.addSample(tom5_ram, tom5_size, tom5_loop, tom5_tune, "tom5");
    TomVoice tom5_voice;
    tom5_voice.Init(tom5_sample);
    tom_voices1.push_back(tom5_voice);
    tom_voices2.push_back(tom5_voice);
    tom_voices3.push_back(tom5_voice);

    Sample tom6_sample;
    tom6_sample.Init(false);
    tom6_sample.addSample(tom6_ram, tom6_size, tom6_loop, tom6_tune, "tom6");
    TomVoice tom6_voice;
    tom6_voice.Init(tom6_sample);
    tom_voices1.push_back(tom6_voice);
    tom_voices2.push_back(tom6_voice);
    tom_voices3.push_back(tom6_voice);

    Sample tom7_sample;
    tom7_sample.Init(false);
    tom7_sample.addSample(tom7_ram, tom7_size, tom7_loop, tom7_tune, "tom7");
    TomVoice tom7_voice;
    tom7_voice.Init(tom7_sample);
    tom_voices1.push_back(tom7_voice);
    tom_voices2.push_back(tom7_voice);
    tom_voices3.push_back(tom7_voice);

}

void initKnobs()
{

    AdcChannelConfig adc[9];

    adc[0].InitSingle(hardware.GetPin(15));     // ADC0 pitch 1
    adc[1].InitSingle(hardware.GetPin(16));     // ADC1 select 1
    adc[2].InitSingle(hardware.GetPin(17));     // ADC2 pitch 2
    adc[3].InitSingle(hardware.GetPin(18));     // ADC3 select 2
    adc[4].InitSingle(hardware.GetPin(24));     // ADC9 pitch 3
    adc[5].InitSingle(hardware.GetPin(20));     // ADC5 select 3
    adc[6].InitSingle(hardware.GetPin(21));     // ADC6 reverb mix
    adc[7].InitSingle(hardware.GetPin(22));     // ADC7 reverb length
    adc[8].InitSingle(hardware.GetPin(23));     // ADC8 reverb lowpass

    hardware.adc.Init(adc, 9);
    hardware.adc.Start();

    trigger1.Init(hardware.GetPin(11), 1000);
    trigger2.Init(hardware.GetPin(12), 1000);
    trigger3.Init(hardware.GetPin(13), 1000);
    cv_type.Init(hardware.GetPin(14), 1000);
}

int main(void)
{
    float samplerate;
    // Init
    hardware.Configure();
    hardware.Init();
    hardware.SetAudioBlockSize(32);
    samplerate = hardware.AudioSampleRate();

    System::Delay(500);

    hardware.StartLog();
    InitSynth(samplerate);

    // Start Callbacks
    initKnobs();
    hardware.StartAudio(audio);

    while(1)
    {

    }
}

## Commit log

2023-10-02 First real commit
    [euro-tomboi.csv, euro-tomboi.kicad_pcb, euro-tomboi.kicad_sch]
2023-10-03 Add missing sample.h
2023-10-03 fix pitch to midi note
    [Tomboi-seed.cpp]
2023-10-03 constexpr for samples
2023-10-03 Fix pitch knob when over 0.5
    [Tomboi-seed.cpp]
2023-11-14 cvToPitch & CV Type fixes
    [Tomboi-seed.cpp]
